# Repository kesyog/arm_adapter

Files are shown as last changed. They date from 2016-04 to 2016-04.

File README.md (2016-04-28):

# arm_adapter

Small addition to Noah's 20-pin to 10-pin ARM JTAG/SWD adapter to include additional connectors in addition to the 10-pin 0.05" connector:
* 6-pin 0.1" through-hole (e.g. Amarok)
* 10-pin 0.1" through-hole (non-standard APC pinout?)
* 10-pin 0.1" through-hole Cortex debug connector (same pin-out as 10-pin 0.05" connector)
* 20-pin 0.05" SMT Debug+Cortex ETM connector

## future improvements

* use shrouded connector for 10-pin 0.05" connector for easier connection
* don't use a right-angle switch?
* fix link to github repo on back silkscreen

## Pictures
### pcb render
TBD
<!---
![front](https://raw.githubusercontent.com/noahp/arm_20to10/master/front.png). . . . . .  ![back](https://raw.githubusercontent.com/noahp/arm_20to10/master/back.png)
-->

### assembly render
TBD
<!---
![top](https://raw.githubusercontent.com/noahp/arm_20to10/master/3drender_top.png)
![iso](https://raw.githubusercontent.com/noahp/arm_20to10/master/3drender_iso.png)
-->
### assembled unit
TBD
<!---
<img src="https://raw.githubusercontent.com/noahp/arm_20to10/master/assembled_picture.jpg" width="480">
-->

## parts

### 10 pin through hole male connector
[digikey](http://www.digikey.com/product-detail/en/te-connectivity-amp-connectors/826656-5/A121773-ND/2276218)  
[digikey](http://www.digikey.com/product-detail/en/20021111-00010T4LF/609-3712-ND/2209072)  
[mouser](http://www.mouser.com/ProductDetail/FCI/20021111-00010T4LF/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)  
[ebay](http://www.ebay.com/itm/12-pcs-Gold-Plated-1-27mm-2x40-80pin-Breakable-Pin-Header-Male-Double-Row-Strip-/370935487630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)  

[shrouded, digikey](http://www.digikey.com/product-detail/en/3220-10-0100-00/1175-1627-ND/3883661)

### 20 pin through hole female connector
[digikey](http://www.digikey.com/product-detail/en/SFH11-PBPC-D10-ST-BK/S9197-ND/1990090)  
[ebay](http://www.ebay.com/itm/20-Pcs-2x10-Double-Row-20-Pins-PCB-Female-Header-2-54mm-/400316132430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)  
[digkey right angle](http://www.digikey.com/product-detail/en/SFH11-PBPC-D10-RA-BK/S9205-ND/1990098)  

### 10-pin (2x5) 0.05" SMT male connector
[digikey](http://www.digikey.com/product-detail/en/harwin-inc/M50-3600542/952-1389-ND/2264370)  

### 20-pin (2x10) 0.05" SMT male connector
[digikey](http://www.digikey.com/product-detail/en/amphenol-fci/20021121-00020C4LF/609-3698-1-ND/2209158)  

### 3.3v ldo
Macrofab stocks a 3.3.V 300mA SOT-23-5 LDO  
[mouser- skyworks sot23-5](http://www.mouser.com/ProductDetail/Skyworks-Solutions-Inc/AAT3223IGU-33-T1/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)  
[mouser- TI sot23-5](http://www.mouser.com/ProductDetail/Texas-Instruments/LP5907MFX-33-NOPB/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)  
[digikey- TI sot23-5](http://www.digikey.com/product-detail/en/TLV70233DBVR/296-32415-1-ND/3505572)  
[digikey- Micrel sot23-5 300mA](http://www.digikey.com/product-detail/en/MIC5504-3.3YM5%20TR/576-4764-1-ND/4864028)  

### beefier ldo
[mouser- ON](http://www.mouser.com/ProductDetail/ON-Semiconductor/NCP1117LPST33T3G/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)  
[mouser- diodes](http://www.mouser.com/ProductDetail/Diodes-Incorporated/AP1117IE33G-13/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)  

### slide switch
[digikey-C&K](http://www.digikey.com/product-detail/en/c-k-components/OS102011MA1QS1/CKN9560-ND/1981431) well-stocked right-angle slide switch  

[mouser- C&K](http://www.mouser.com/ProductDetail/CK-Components/PCM12SMTR/?qs=sGAEpiMZZMsqIr59i2oRcvc9UQrBbcoBkFYgnQFYwWU%3d)  
[digikey- Copal](http://www.digikey.com/product-detail/en/CUS-12TB/563-1102-1-ND/1124231)  
[mouser- ALPS](http://www.mouser.com/ProductDetail/ALPS/SSSS810701/?qs=sGAEpiMZZMtHXLepoqNyVe%252bcQMRoBF1BAzyvwoNmgBo%3d)

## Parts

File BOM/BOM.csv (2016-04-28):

#Designator | X-Loc | Y-Loc | Rotation | Side | Type | X-Size | Y-Size | Value | Footprint | Populate | MPN
C1 |  |  |  | top | SMT | 60 | 30 | 1uF 10% 25V | C0603 | 1 | MF-CAP-0603-1uF
C2 |  |  |  | top | SMT | 60 | 30 | 1uF 10% 25V | C0603 | 1 | MF-CAP-0603-1uF
D1 |  |  |  | top | SMT | 60 | 30 | Red LED | LED0603 | 1 | MF-LED-0603-RED
D2 |  |  |  | top | SMT | 60 | 30 | Green LED | LED0603 | 1 | MF-LED-0603-GREEN
J2 |  |  |  | top | SMT |  |  | 20-pin (2x10) 0.05" SMT header |  | 1 | SAM8794-ND (Digikey) | 20021121-00020C4LF
J4 |  |  |  | top | SMT |  |  | 10-pin (2x5) 0.05" SMT header (FTSH-105-01-F-DV) |  | 1 | SAM8795-ND (Digikey) | M50-3600542
R1 |  |  |  | top | SMT | 60 | 30 | 1kohm | R0603 | 1 | MF-RES-0603-1K
R2 |  |  |  | top | SMT | 60 | 30 | 470ohm | R0603 | 1 | MF-RES-0603-470
U1 |  |  |  | top | SMT |  |  | 3.3V, 300mA LDO | SOT-23-5 | 1 | MF-REG-SOT235-3.3V-300mA
J1 |  |  |  | top | PTH |  |  | 20-pin (2x10) Right-angle connector 0.1" pitch |  | 1 | S9205-ND (Digikey)
J3 |  |  |  | top | PTH |  |  | 10-pin (2x5) 0.1" unshrouded header |  | 1 | e.g. 609-3243-ND (Digikey) | 826656-5
J5 |  |  |  | top | PTH |  |  | 10-pin (2x5) 0.1" unshrouded header |  | 1 | e.g. 609-3243-ND (Digikey) | 826656-5
J6 |  |  |  | top | PTH |  |  |  |  | 1 | MF-CON-2.54mm-2x3
SW1 |  |  |  | top | PTH |  |  | Slide Switch: C&K SS-12D07-VG 4 NS GA PA | custom | 1 | CKN10397-ND (Digikey) | OS102011MA1QS1

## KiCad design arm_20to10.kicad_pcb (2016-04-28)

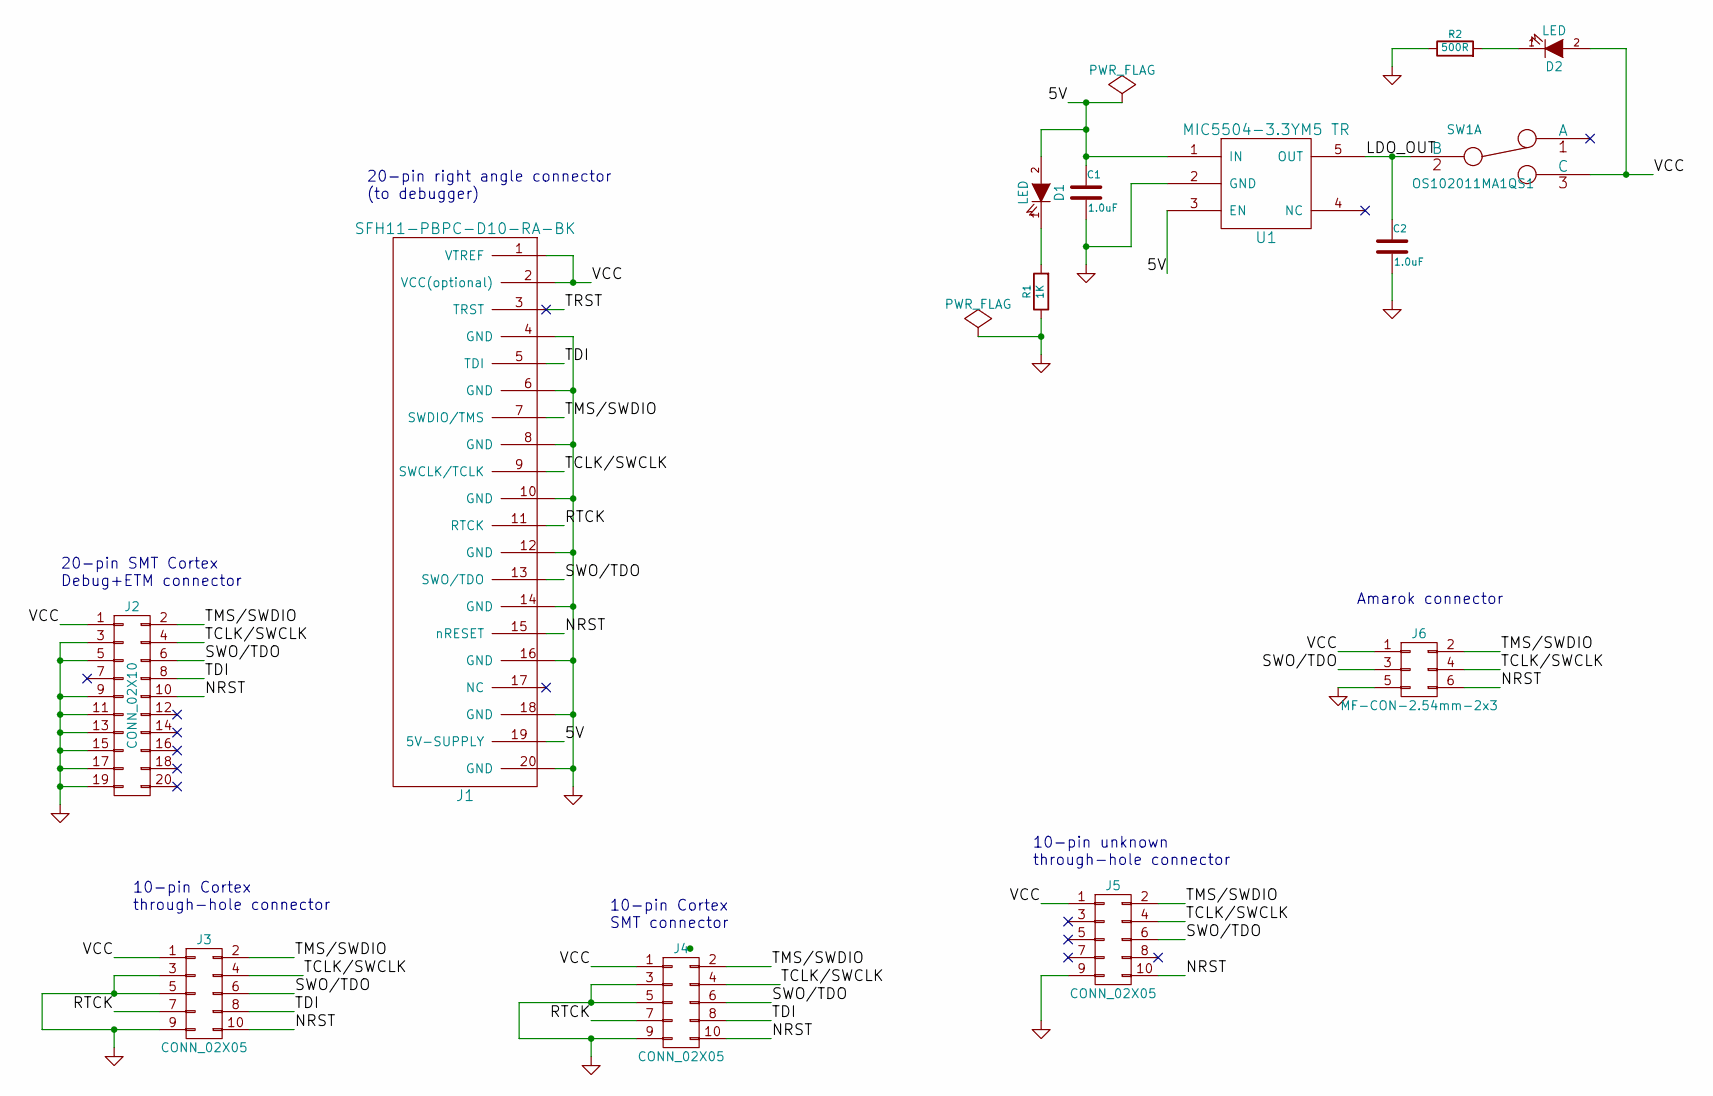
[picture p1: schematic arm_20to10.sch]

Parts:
C1, C2: 1.0uF; SMD_0603_C
D1, D2: LED; SMD_0603_LED
J1: SFH11-PBPC-D10-RA-BK; ARM_20_PIN_TH_RIGHTANGLE; MFG PN SFH11-PBPC-D10-RA-BK
J2: CONN_02X10; ARM_20_PIN_SMT
J3, J5: CONN_02X05; Pin_Header_Straight_2x05
J4: CONN_02X05; ARM_10_PIN_SMT
J6: MF-CON-2.54mm-2x3; Pin_Header_Straight_2x03
R1: 1K; SMD_0603_R
R2: 500R; SMD_0603_R
SW1: OS102011MA1QS1; SS-12D07-VG-kes; MFG PN SS-12D07-VG 4 NS GA PA
U1: MIC5504-3.3YM5 TR; sot23-5_noah

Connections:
/5V: C1.1, D1.2 (A), J1.19 (5V-SUPPLY), U1.1 (IN), U1.3 (EN)
/LDO_OUT: C2.1, SW1.2 (B), U1.5 (OUT)
/NRST: J1.15 (nRESET), J2.10, J3.10, J4.10, J5.10, J6.6
/RTCK: J1.11 (RTCK), J3.7, J4.7
/SWO/TDO: J1.13 (SWO/TDO), J2.6, J3.6, J4.6, J5.6, J6.3
/TCLK/SWCLK: J1.9 (SWCLK/TCLK), J2.4, J3.4, J4.4, J5.4, J6.4
/TDI: J1.5 (TDI), J2.8, J3.8, J4.8
/TMS/SWDIO: J1.7 (SWDIO/TMS), J2.2, J3.2, J4.2, J5.2, J6.2
/TRST: J1.3 (TRST)
/VCC: D2.2 (A), J1.1 (VTREF), J1.2 (VCC(optional)), J2.1, J3.1, J4.1, J5.1, J6.1, SW1.3 (C)
GND: C1.2, C2.2, J1.4 (GND), J1.6 (GND), J1.8 (GND), J1.10 (GND), J1.12 (GND), J1.14 (GND), J1.16 (GND), J1.18 (GND), J1.20 (GND), J2.3, J2.5, J2.9, J2.11, J2.13, J2.15, J2.17, J2.19, J3.3, J3.5, J3.9, J4.3, J4.5, J4.9, J5.9, J6.5, R1.1, R2.1, U1.2 (GND)
unnamed: D1.1 (K), R1.2
unnamed: D2.1 (K), R2.2

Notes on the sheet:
Amarok connector
20-pin right angle connector (to debugger)
20-pin SMT Cortex Debug+ETM connector
10-pin Cortex through-hole connector
10-pin Cortex SMT connector
10-pin unknown through-hole connector

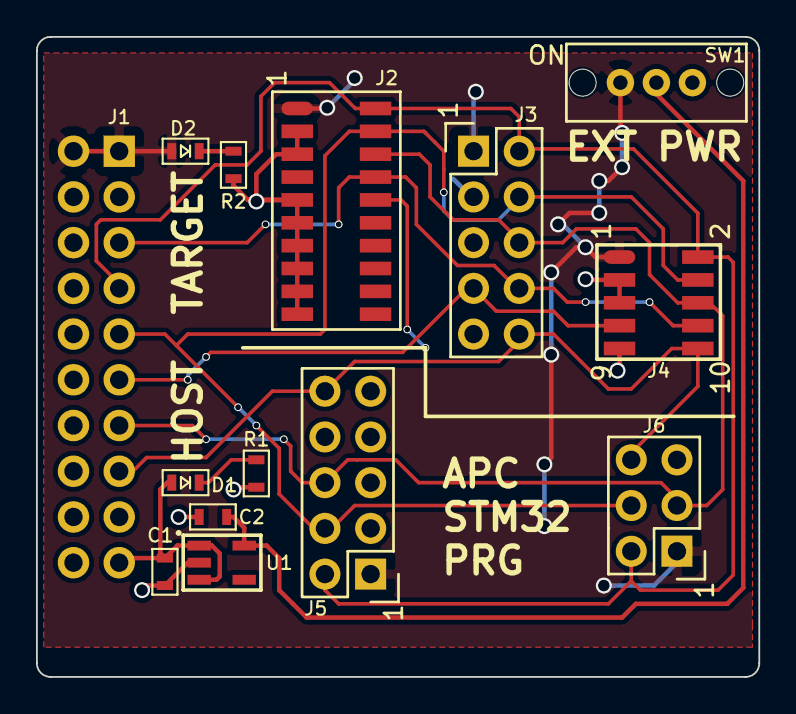
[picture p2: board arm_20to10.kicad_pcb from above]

Board: 2 copper layers, 40.1 x 35.6 mm, 14 parts (0 on the bottom side), 12 nets.

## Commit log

2016-04-28 Updated Kicad project files for v2.2 build of board. Add my custom library as a submodule. Probably messed up some git commands
    [arm_20to10.kicad_pcb, arm_20to10.sch]
2016-04-28 add new gerber and BOM
    [BOM.csv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]
2016-04-28 update project to look in my library for my custom parts rather than Noah's
    [arm_20to10.sch]
